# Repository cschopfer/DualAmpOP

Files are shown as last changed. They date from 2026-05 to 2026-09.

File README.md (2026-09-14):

# DualAmpOP

[cschopfer/DualAmpOP](https://github.com/cschopfer/DualAmpOP)

Un petit PCB pour avoir un ampli-op double disponible pour vos bricolages sur breadboard.

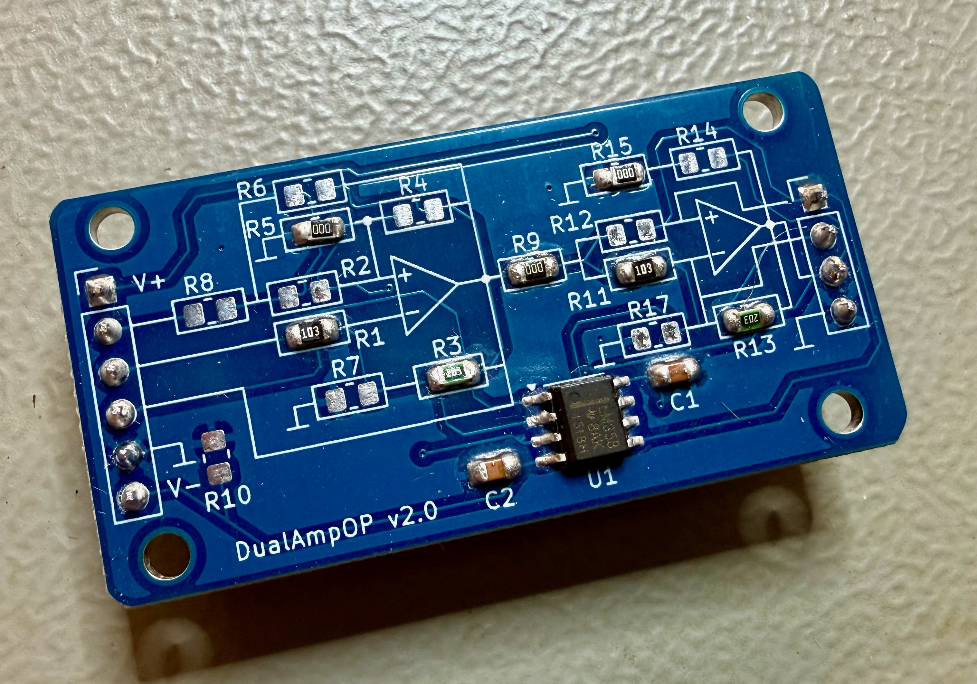
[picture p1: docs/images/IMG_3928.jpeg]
PCB DualAmpOP v2.0


**Statut :** prototype v2.0 monté et testé, fonctionne très bien.
Cette v2.0 remplace une v1 qui n'a jamais été produite.

## Le principe

Le PCB accepte tout double ampli-op compatible broche à broche en boîtier
SOIC-8 — LM358, MCP6002, etc.

Chaque étage dispose d'un réseau de résistances (R1 à R8 pour le premier
étage, R9 à R17 pour le second, sur le même principe) qu'il suffit de
câbler pour obtenir la topologie voulue :

- **n.m.** — ne rien monter
- **0 Ω** — un pont (connexion directe)
- **valeur** — une vraie résistance, pour régler un gain ou une fréquence de coupure

## Configurations

| Montage | R1 | R2 | R3 | R4 | R5 | R6 | R7 | R8 | Gain / formule |
|---|---|---|---|---|---|---|---|---|---|
| Inverseur | valeur | n.m. | valeur | n.m. | 0 Ω | n.m. | n.m. | n.m. | `Vout = −Vin·(R3/R1)` |
| Non-inverseur | n.m. | 0 Ω | valeur | n.m. | n.m. | n.m. | valeur | 0 Ω | `Vout = Vin·(1 + R3/R7)` |
| Transimpédance | 0 Ω | n.m. | Rf | n.m. | 0 Ω | n.m. | n.m. | n.m. | `Vout = −Iin·R3` |
| Suiveur | n.m. | 0 Ω | 0 Ω | n.m. | n.m. | n.m. | n.m. | 0 Ω | `Vout = Vin` |
| Passe-bas actif (intégrateur) | R | n.m. | C* | n.m. | n.m. | n.m. | n.m. | n.m. | `fc = 1/(2πRC)` |
| Passe-haut actif | — | — | — | — | — | — | — | — | à venir |
| Sallen-Key | — | — | — | — | — | — | — | — | à venir |

\* Pour les filtres actifs, la résistance concernée est remplacée par un
condensateur céramique 0805 de même taille.

### Alimentation symétrique ou asymétrique

R10 relie le rail V- à la masse.

- **Non montée** : alimentation symétrique (Vcc+ / Vcc-)
- **Montée à 0 Ω** : alimentation asymétrique, entre Vcc et GND

## Arborescence

```
hardware/
  DualAmpOP.kicad_pro
  exports/
    PDF/
    gerbers/
    3D/
docs/
  images/
    IMG_3928.jpeg
```

## Licence

À définir.

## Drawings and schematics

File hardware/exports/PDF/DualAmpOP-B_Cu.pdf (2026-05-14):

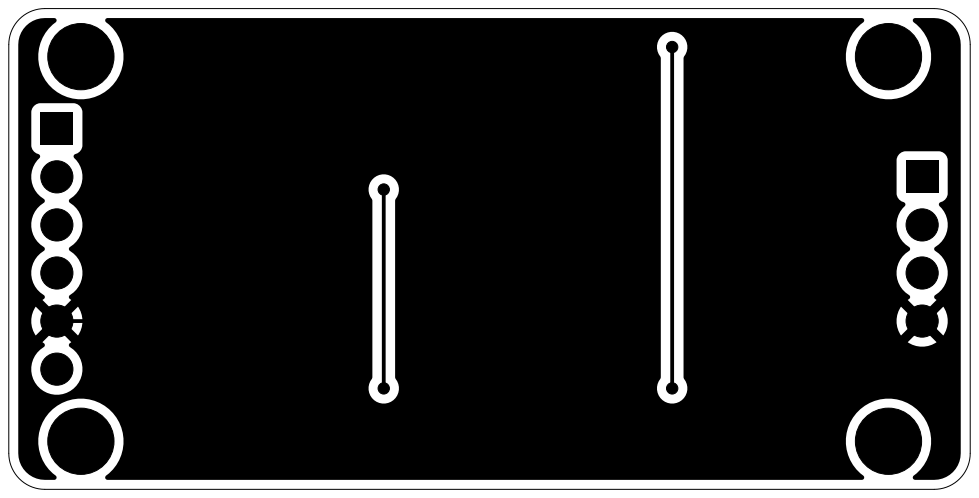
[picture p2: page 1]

Date | 14.05.2026 KiCad E.D.A. 10.0.1 Page | Rev: A4 2.0

2/9 | Dessiné par DualAmpOP | Général Fichier | DualAmpOP.kicad_pcb Page Cédric Schöpfer Feuille

Projet Digipict.ch

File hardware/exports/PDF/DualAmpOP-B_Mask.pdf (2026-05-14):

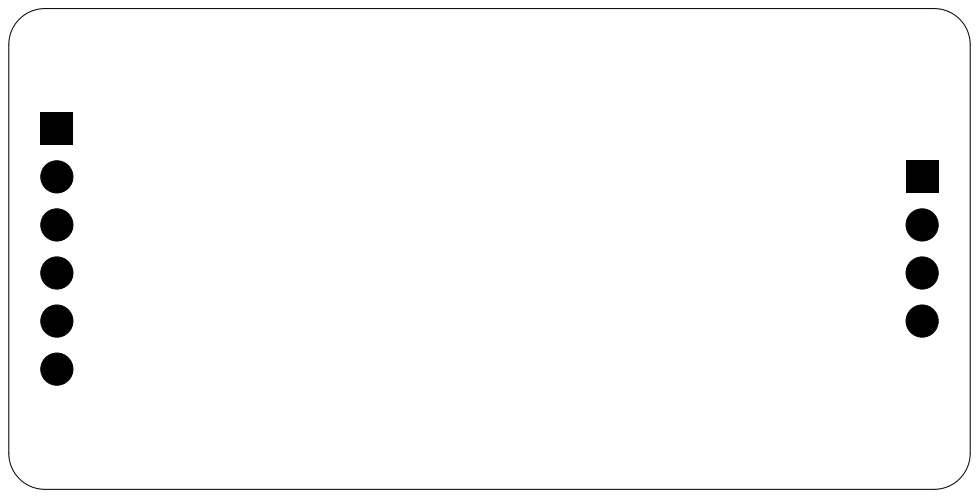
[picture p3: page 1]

Date | 14.05.2026 KiCad E.D.A. 10.0.1 Page | Rev: A4 2.0

8/9 | Dessiné par DualAmpOP | Général Fichier | DualAmpOP.kicad_pcb Page Cédric Schöpfer Feuille

Projet Digipict.ch

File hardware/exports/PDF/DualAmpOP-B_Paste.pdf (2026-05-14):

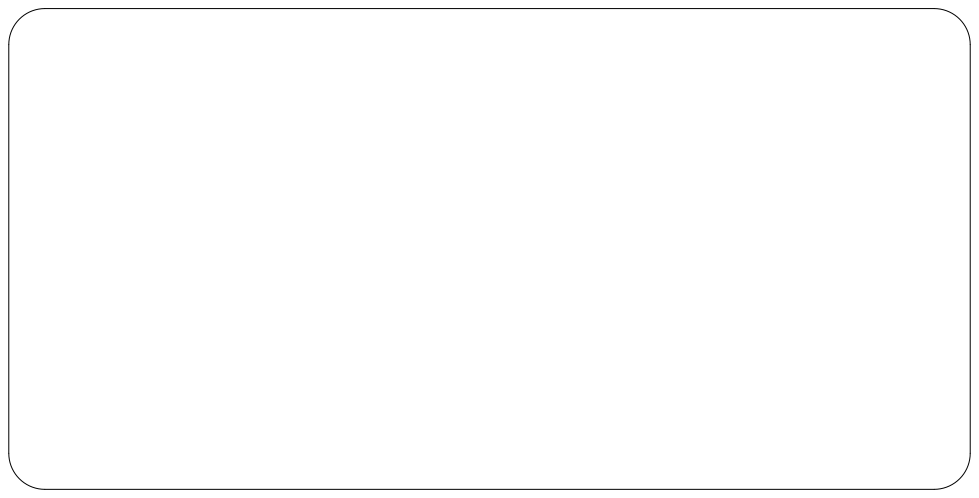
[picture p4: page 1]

Date | 14.05.2026 KiCad E.D.A. 10.0.1 Page | Rev: A4 2.0

4/9 | Dessiné par DualAmpOP | Général Fichier | DualAmpOP.kicad_pcb Page Cédric Schöpfer Feuille

Projet Digipict.ch

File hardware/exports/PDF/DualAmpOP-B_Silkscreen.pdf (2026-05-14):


Date | 14.05.2026 KiCad E.D.A. 10.0.1 Page | Rev: A4 2.0

6/9 | Dessiné par DualAmpOP | Général Fichier | DualAmpOP.kicad_pcb Page Cédric Schöpfer Feuille

Projet Digipict.ch

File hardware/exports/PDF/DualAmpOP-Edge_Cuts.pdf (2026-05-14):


Date | 14.05.2026 KiCad E.D.A. 10.0.1 Page | Rev: A4 2.0

9/9 | Dessiné par DualAmpOP | Général Fichier | DualAmpOP.kicad_pcb Page Cédric Schöpfer Feuille

Projet Digipict.ch

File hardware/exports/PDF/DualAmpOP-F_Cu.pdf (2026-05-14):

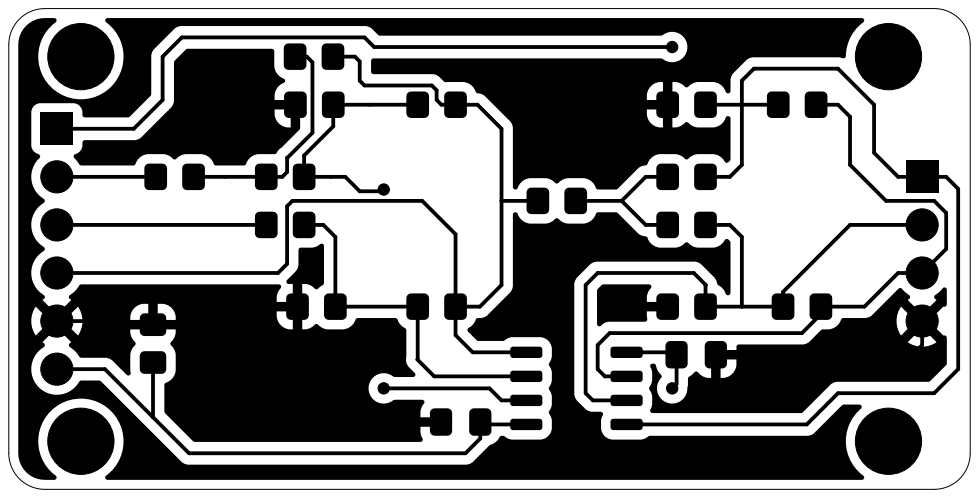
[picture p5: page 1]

Date | 14.05.2026 KiCad E.D.A. 10.0.1 Page | Rev: A4 2.0

1/9 | Dessiné par DualAmpOP | Général Fichier | DualAmpOP.kicad_pcb Page Cédric Schöpfer Feuille

Projet Digipict.ch

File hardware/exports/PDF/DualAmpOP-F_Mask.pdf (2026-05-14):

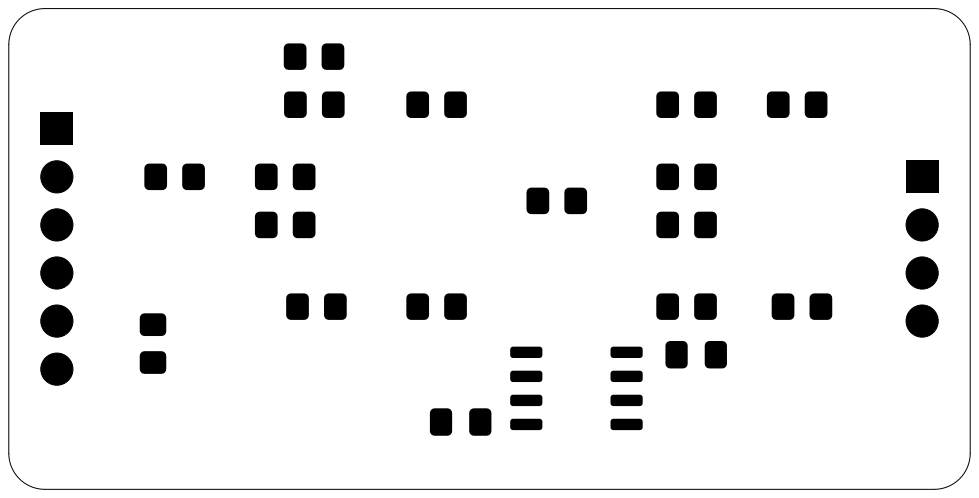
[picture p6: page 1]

Date | 14.05.2026 KiCad E.D.A. 10.0.1 Page | Rev: A4 2.0

7/9 | Dessiné par DualAmpOP | Général Fichier | DualAmpOP.kicad_pcb Page Cédric Schöpfer Feuille

Projet Digipict.ch

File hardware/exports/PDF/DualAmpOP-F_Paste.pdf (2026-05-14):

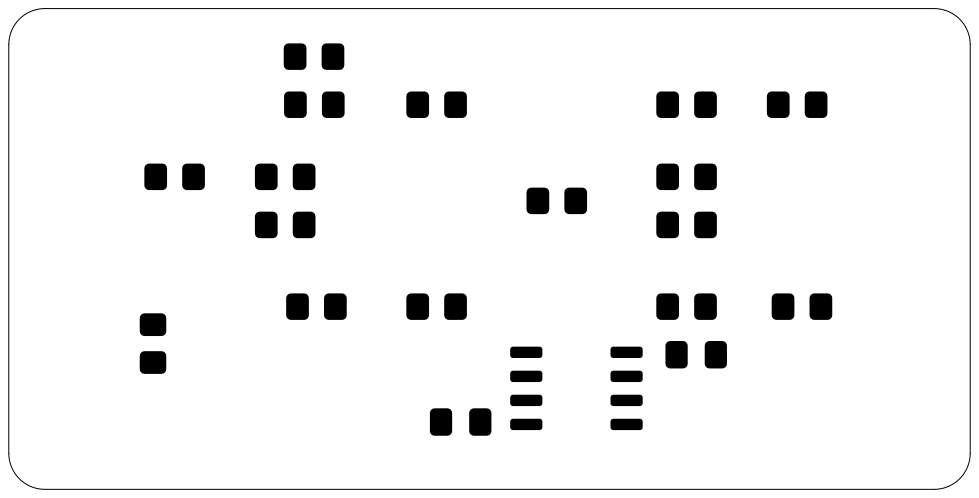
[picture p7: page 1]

Date | 14.05.2026 KiCad E.D.A. 10.0.1 Page | Rev: A4 2.0

3/9 | Dessiné par DualAmpOP | Général Fichier | DualAmpOP.kicad_pcb Page Cédric Schöpfer Feuille

Projet Digipict.ch

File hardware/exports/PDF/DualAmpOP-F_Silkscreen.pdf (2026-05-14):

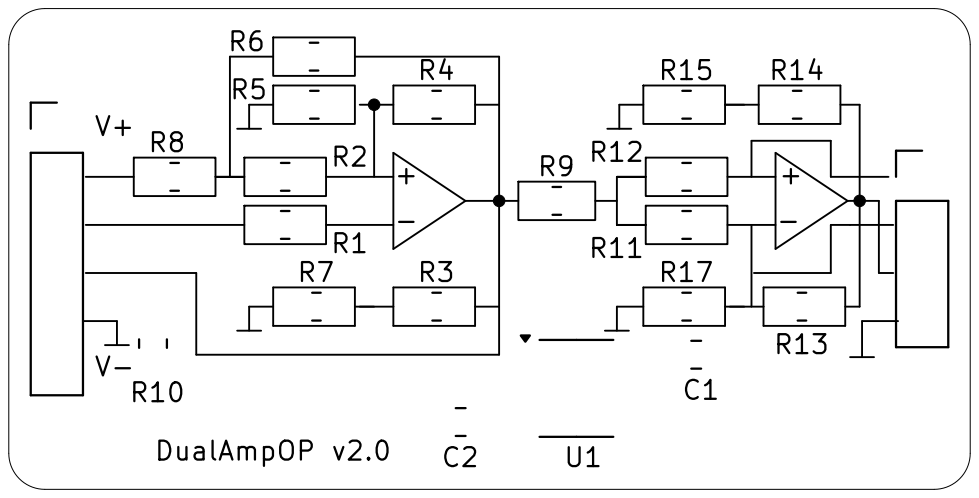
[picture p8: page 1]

Date | 14.05.2026 KiCad E.D.A. 10.0.1 Page | Rev: A4 2.0

5/9 | Dessiné par DualAmpOP | Général Fichier | DualAmpOP.kicad_pcb Page Cédric Schöpfer Feuille

Projet Digipict.ch

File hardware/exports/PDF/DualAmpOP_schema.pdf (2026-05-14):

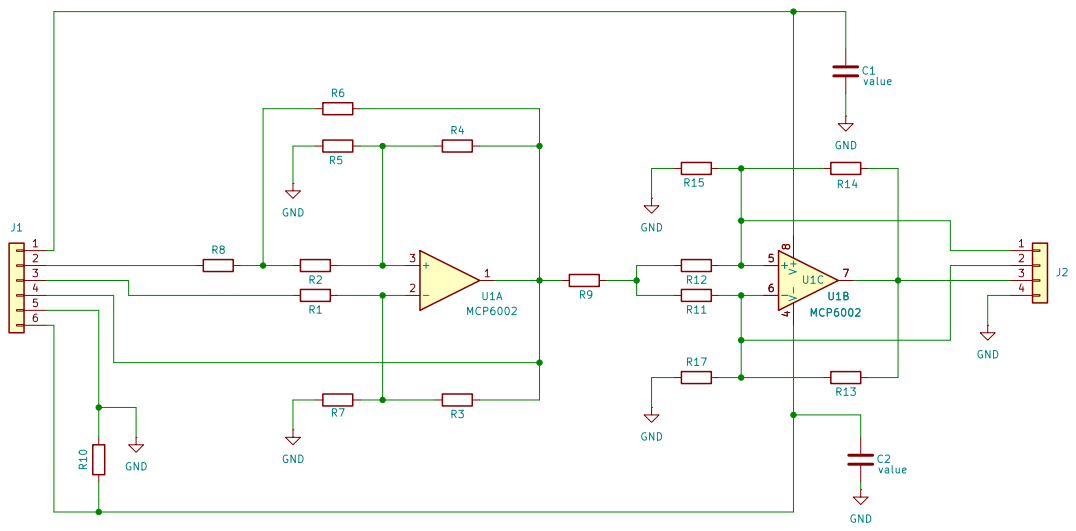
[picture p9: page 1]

Fichier Date | DualAmpOP.kicad_sch Page Cédric Schöpfer Les resistances 0805 peuvent etre remplacé par des condensateurs 12.05.2026 KiCad E.D.A. 10.0.1 Page | Rev: A4 2.0
1/1 | Dessiné par Ampli-OP | Général

Projet Digipict.ch

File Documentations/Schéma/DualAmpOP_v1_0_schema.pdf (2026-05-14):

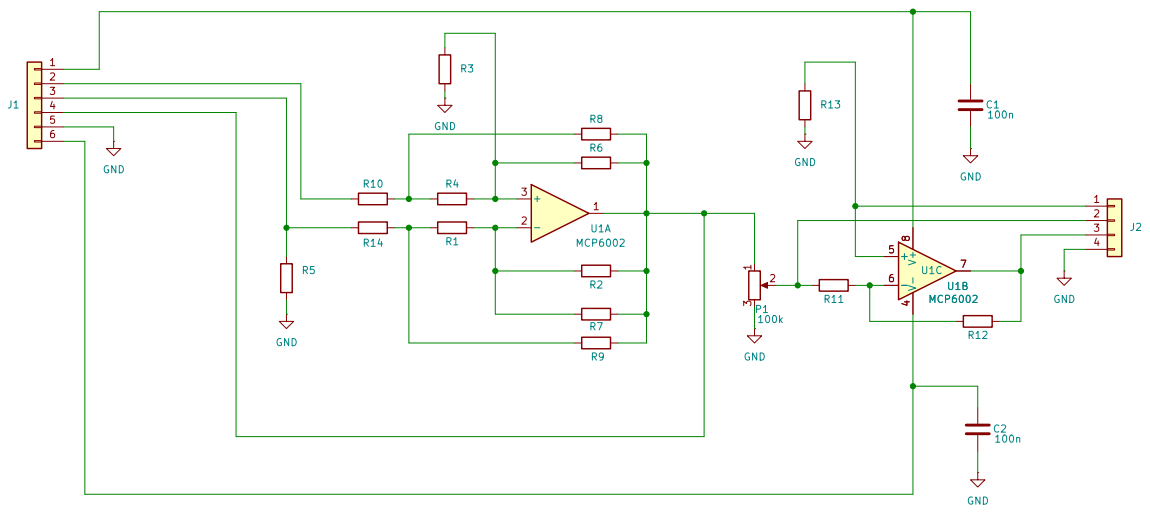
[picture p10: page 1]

Fichier Date | DualAmpOP.kicad_sch Page Cédric Schöpfer Carte générique : Valeur a modifier par projet Feuille 2025-12-21 KiCad E.D.A. 10.0.1 Page | Rev: A4 1.0
1/1 | Dessiné par DualAmpOP | Général

Projet Digipict.ch

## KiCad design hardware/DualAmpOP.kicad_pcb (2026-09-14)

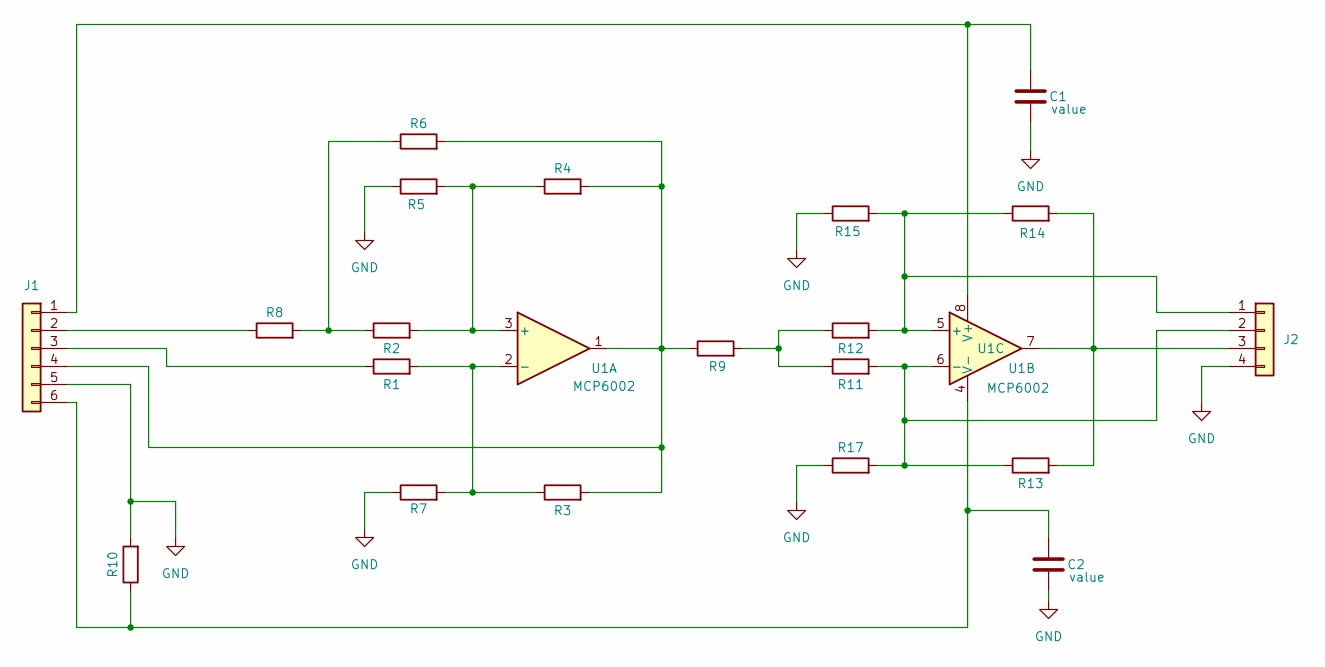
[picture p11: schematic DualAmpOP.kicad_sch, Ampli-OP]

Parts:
C1, C2: value; C_0805_2012Metric_Pad1.18x1.45mm_HandSolder
J1: PinHeader_1x06_P2.54mm_Vertical
J2: PinHeader_1x04_P2.54mm_Vertical
R1, R2, R3, R5, R11, R12, R13, R15: R; R_0805_2012Metric_Pad1.20x1.40mm_HandSolder
R4, R6, R7, R8, R9, R10, R14, R17: value; R_0805_2012Metric_Pad1.20x1.40mm_HandSolder
U1: MCP6002; SOIC-8_3.9x4.9mm_P1.27mm

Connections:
GND: C1.2, C2.2, J1.5, J2.4, R5.1, R7.1, R10.2, R15.1, R17.1
unnamed: C1.1, J1.1, U1.8 (V+)
unnamed: J1.2, R8.1
unnamed: J1.3, R1.1
unnamed: J1.4, R3.2, R4.2, R6.2, R9.1, U1.1
unnamed: C2.1, J1.6, R10.1, U1.4 (V-)
unnamed: J2.1, R12.2, R14.1, R15.2, U1.5 (+)
unnamed: J2.2, R11.2, R13.1, R17.2, U1.6 (-)
unnamed: J2.3, R13.2, R14.2, U1.7
unnamed: R2.1, R6.1, R8.2
unnamed: R9.2, R11.1, R12.1
unnamed: R2.2, R4.1, R5.2, U1.3 (+)
unnamed: R1.2, R3.1, R7.2, U1.2 (-)

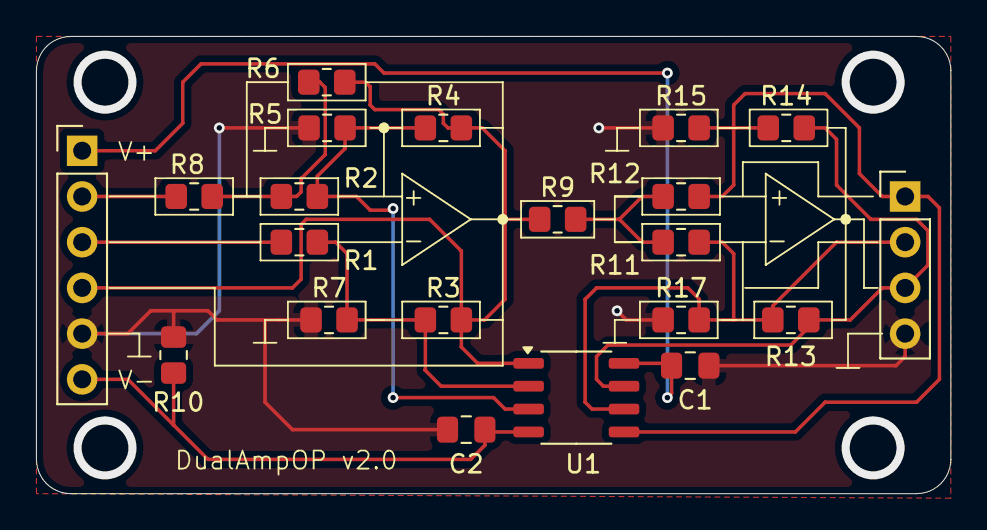
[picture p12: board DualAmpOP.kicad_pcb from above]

Board: 2 copper layers, 50.8 x 25.4 mm, 21 parts (0 on the bottom side), 13 nets.

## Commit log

2026-01-04 Premier commit v1
    [ampli_op.kicad_pcb, ampli_op.kicad_sch]
2026-05-14 Finalisation V1 + renommage projet
    [DualAmpOP-B_Cu.gbr, DualAmpOP-B_Mask.gbr, DualAmpOP-B_Paste.gbr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]
2026-05-14 Nouvelle version 2 plus pratique
    [DualAmpOP.kicad_pcb, DualAmpOP.kicad_sch]
2026-05-14 Modification R6 pour filtre Sallen-key
    [DualAmpOP-B_Cu.gbr, DualAmpOP-B_Mask.gbr, DualAmpOP-B_Paste.gbr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]
2026-09-14 Reorganisation repertoire
    [DualAmpOP-B_Cu.gbr, DualAmpOP-B_Mask.gbr, DualAmpOP-B_Paste.gbr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]
2026-09-14 Ajout du Readme
    [DualAmpOP-B_Cu.gbr, DualAmpOP-B_Mask.gbr, DualAmpOP-B_Paste.gbr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]
